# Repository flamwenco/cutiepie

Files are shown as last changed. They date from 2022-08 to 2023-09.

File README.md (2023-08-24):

# cutiepie
A funky little 10.5u with dual 1.75u spacebars. Support for 3u and 4u spacebar bottom row layouts has been added, as well as support for 2x2u's using the 4u top. 2u's are forced stabless, otherwise a redesign of the pcb layout would have been necessitated.

## Layout options


[An ortho pcb](https://github.com/flamwenco/cutiepie/tree/mistress/KiCad%20Project%20Files/ortho%20pcb) is also now available as well.

The vial firmware has been updated to visually support uniform stagger, regular stagger, and ortho, but your existing firmware will also work since the pinouts have not changed.

## Production files
The current version of this pcb that supports all above layouts has been ordered and confirmed to work, but I am not responsible for your orders with a pcb manu. No support will be provided, order at your own risk.

You will also need a daughterboard for this keyboard. It was designed around the ai03 C3 daughterboard.

## Case files
Case files are provided in this repo for 3d printing.

The case is designed around m2 screws and heatset inserts. The top will need 6 M2x4mm inserts, and M2x5mm screws. The daughterboard mounting in the bottom will need 4 M2x3mm inserts, and M2x4mm screws.

The cutouts for the feet in the bottom of the case are sized for primekb feet.

## Special Thanks
- [SST60](https://github.com/dededecline/SST60), this project heavily lifts the rp2040 wiring from it, without it I wouldn't have even known where to start
- 4u spacebar footprint is by [drhigsby](https://github.com/drhigsby)
- Thick plates were created from plates generated by bears' [Keyboard Case Generator](https://github.com/gleorepo/Keyboard-Case-Generator)
- Symmetric case and plate were modified by Chronomap

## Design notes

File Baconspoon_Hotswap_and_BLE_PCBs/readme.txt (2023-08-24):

Included in this directory are several PCB and plate files for Cutiepie by Flamwenco. Pay close attention to compatibility notes. These PCB's and plates are NOT compatible with the original 2x1.75u and 3u case tops, or the original non-symmetrical case bottom. Choose a plate option that will support your desired layout, including stabilizers.
	
-Hotswap, Uniform Stagger
	-Integrated RP2040
	-No ISO Enter support
	-Uses uniform 0.25u stagger, as with the original cutiepie
	-Support for both 2u x 2 and 4u stabilizers.
	-Requires the symmetrical uniform or dual stagger plate for 2u stabilizer support.
	-Requires the symmetrical top and bottom cases with only 2x2u or 4u spacebar support.
	-Compatible with original "cutiepie2040" PCB firmware due to 1-for-1 pinout match.

-Hotswap, Standard Stagger
	-Integrated RP2040
	-No ISO Enter support
	-Option for uniform 0.25u stagger, or traditional 0.5u stagger between the "A" and "Z" row.
	-Support for both 2u x 2 and 4u stabilizers.
	-Requires the symmetrical standard or dual stagger plate for 2u stabilizer support.
	-Requires the symmetrical top and bottom cases with only 2x2u or 4u spacebar support.
	-Compatible with original "cutiepie2040" PCB firmware due to 1-for-1 pinout match.

-Solder Only, Dual Stagger (Uniform and Standard) BLE
	-Integrated nRF52840 via Holyiot-18010-nRF52840 module
	-No ISO Enter support
	-Option for traditional 0.5u stagger between the "A" and "Z" row.
	-Support for both 2u x 2 and 4u stabilizers.
	-Requires the symmetrical standard or dual stagger plate for 2u stabilizer support.
	-Requires the symmetrical top and bottom cases with only 2x2u or 4u spacebar support.
	-Custom ZMK firmware

-Dual Stagger Plate
	-Maintains ISO switch and stabilizers support for future compatibility with symmetrical case PCBs supporting ISO Enter.
	-"Z" row switch cutouts support both standard and uniform stagger.
	-May be difficult to achieve perfect left-to-right alignment with 3-pin switches.
	-Gerbers for FR4 plates included with KiCad project files.

-Standard Stagger and Uniform Stagger Plates
	-Maintains ISO switch and stabilizers support for future compatibility with symmetrical case PCBs supporting ISO Enter.
	-Separate plates for each stagger option for better alignment with 3-pin switches.
	-Gerbers for FR4 plates included with KiCad project files.

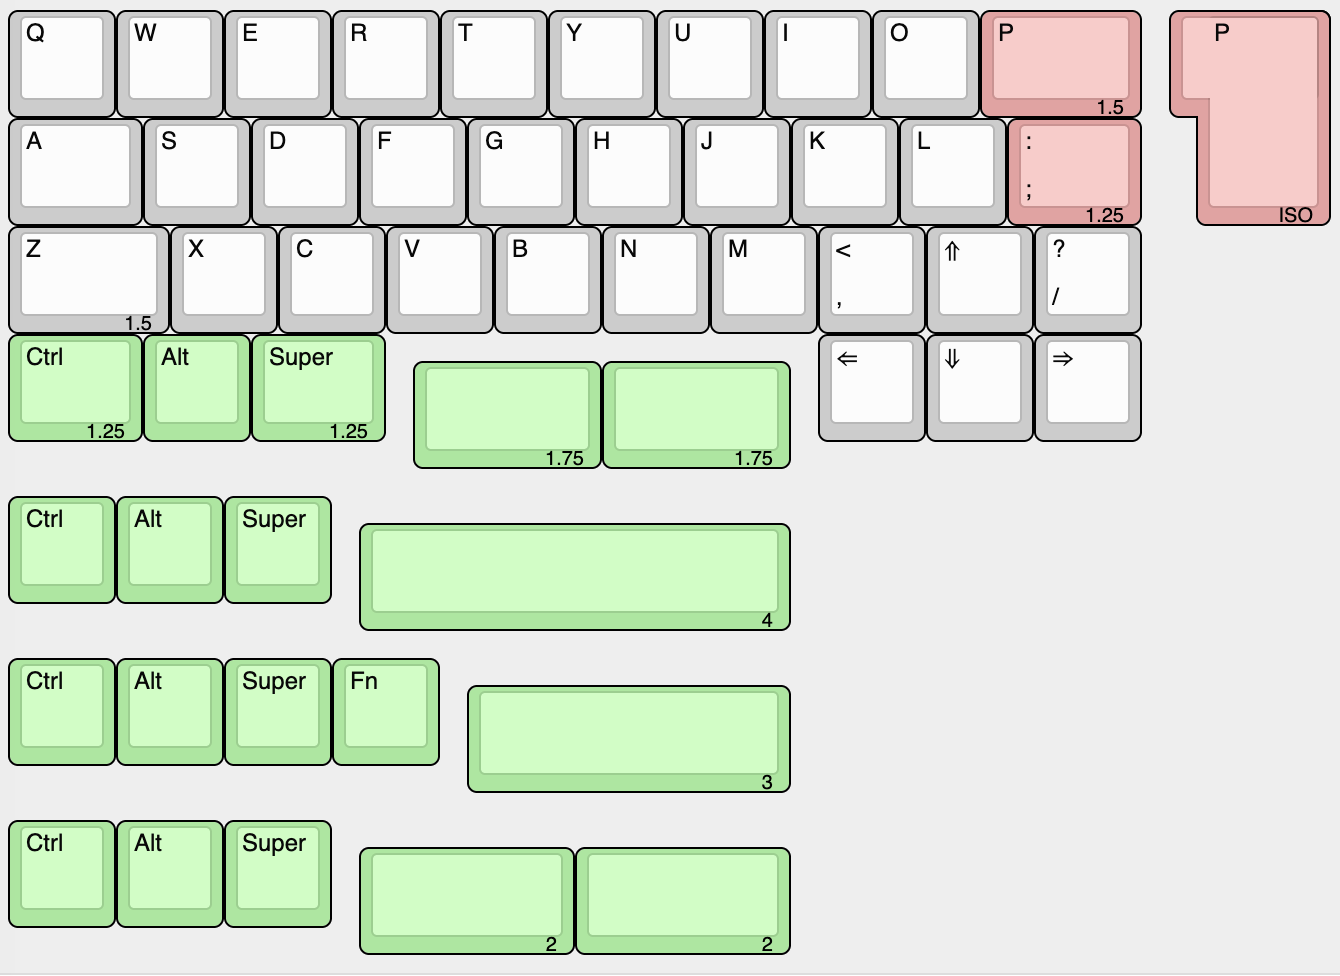
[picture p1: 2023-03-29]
layouts.png

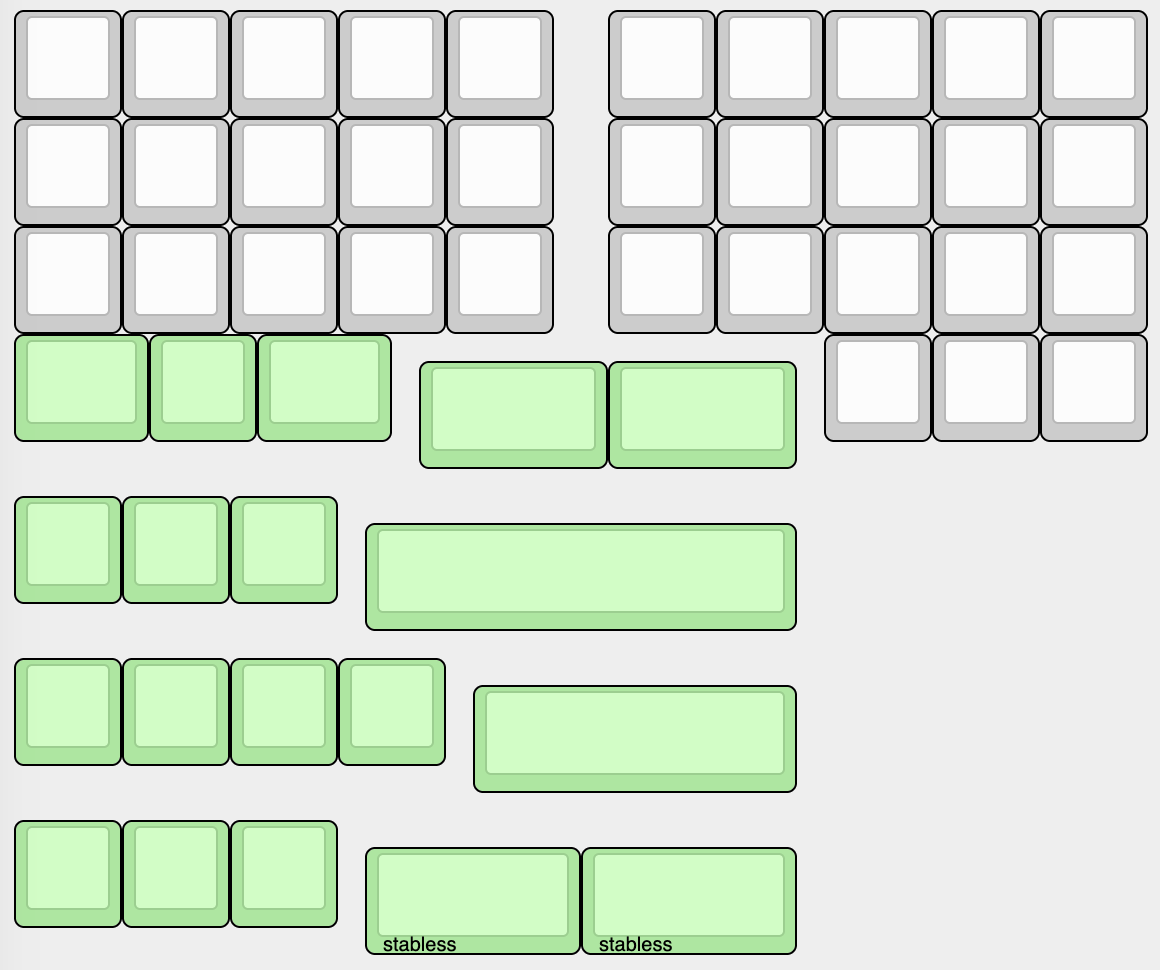
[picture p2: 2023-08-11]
KiCad Project Files/ortho pcb/ortho layouts.png

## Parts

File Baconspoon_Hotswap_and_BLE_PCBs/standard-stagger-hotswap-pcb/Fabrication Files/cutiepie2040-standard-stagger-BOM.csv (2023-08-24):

Comment | Designator | Footprint | JLCPCB Part#(optional)
5K1 | R_Flash2 | R_0402_1005Metric | C103086
5K1 | R_Flash3 | R_0402_1005Metric | C103086
5K1 | R_RST1 | R_0402_1005Metric | C103086
10uF | C_3V-Decoup1 | C_0402_1005Metric | C15525
22pF | C_Crystal1 | C_0402_1005Metric | C1555
22pF | C_Crystal2 | C_0402_1005Metric | C1555
SM04B-SRSS-TB(LF)(SN) | J1 | JST_SH_SM04B-SRSS-TB_1x04-1MP_P1.00mm_Horizontal | C160404
RP2040 | U1 | RP2040-QFN-56 | C2040
27 | R_DATA1 | R_0402_1005Metric | C25100
27 | R_DATA2 | R_0402_1005Metric | C25100
W25Q128JVS | U2 | SOIC-8_5.23x5.23mm_P1.27mm | C2613930
0.1uF | C_1V-Decoup2 | C_0402_1005Metric | C2655418
0.1uF | C_1V-Decoup3 | C_0402_1005Metric | C2655418
0.1uF | C_3V-Decoup3 | C_0402_1005Metric | C2655418
0.1uF | C_3V-Decoup4 | C_0402_1005Metric | C2655418
0.1uF | C_3V-Decoup5 | C_0402_1005Metric | C2655418
0.1uF | C_3V-Decoup6 | C_0402_1005Metric | C2655418
0.1uF | C_3V-Decoup7 | C_0402_1005Metric | C2655418
0.1uF | C_3V-Decoup8 | C_0402_1005Metric | C2655418
0.1uF | C_3V-Decoup9 | C_0402_1005Metric | C2655418
0.1uF | C_Flash1 | C_0402_1005Metric | C2655418
1K | R_Crystal1 | R_0402_1005Metric | C279987
1K | R_Flash1 | R_0402_1005Metric | C279987
CPG151101S11 | MX1 | MXOnly-1U-Hotswap | C2803348
CPG151101S11 | MX10 | MXOnly-1U-Hotswap | C2803348
CPG151101S11 | MX11 | MXOnly-1U-Hotswap | C2803348
CPG151101S11 | MX12 | MXOnly-1U-Hotswap | C2803348
CPG151101S11 | MX13 | MXOnly-1U-Hotswap | C2803348
CPG151101S11 | MX14 | MXOnly-1U-Hotswap | C2803348
CPG151101S11 | MX15 | MXOnly-1U-Hotswap | C2803348
CPG151101S11 | MX16 | MXOnly-1U-Hotswap | C2803348
CPG151101S11 | MX17 | MXOnly-1U-Hotswap | C2803348
CPG151101S11 | MX18 | MXOnly-1U-Hotswap | C2803348
CPG151101S11 | MX19 | MXOnly-2U-Hotswap-ReversedStabilizers | C2803348
CPG151101S11 | MX2 | MXOnly-1.25U-Hotswap | C2803348
CPG151101S11 | MX20 | MXOnly-1U-Hotswap | C2803348
CPG151101S11 | MX21 | MXOnly-1U-Hotswap | C2803348
CPG151101S11 | MX22 | MXOnly-1U-Hotswap | C2803348
CPG151101S11 | MX23 | MXOnly-2U-Hotswap-ReversedStabilizers | C2803348
CPG151101S11 | MX24 | MXOnly-1U-Hotswap | C2803348
CPG151101S11 | MX25 | MXOnly-1U-Hotswap | C2803348
CPG151101S11 | MX26 | MXOnly-1U-Hotswap | C2803348
CPG151101S11 | MX27 | MXOnly-1U-Hotswap | C2803348
CPG151101S11 | MX28 | MXOnly-1U-Hotswap | C2803348
CPG151101S11 | MX29 | MXOnly-1U-Hotswap | C2803348
CPG151101S11 | MX3 | MXOnly-1.5U-Hotswap | C2803348
CPG151101S11 | MX30 | MXOnly-1U-Hotswap | C2803348
CPG151101S11 | MX31 | MXOnly-1U-Hotswap | C2803348
CPG151101S11 | MX32 | MXOnly-1U-Hotswap | C2803348
CPG151101S11 | MX33 | MXOnly-1U-Hotswap | C2803348
CPG151101S11 | MX34 | MXOnly-1U-Hotswap | C2803348
CPG151101S11 | MX35 | MXOnly-1.5U-Hotswap | C2803348
CPG151101S11 | MX36 | MXOnly-1.25U-Hotswap | C2803348
CPG151101S11 | MX37 | MXOnly-1U-Hotswap | C2803348
CPG151101S11 | MX38 | MXOnly-1U-Hotswap | C2803348
CPG151101S11 | MX4 | MXOnly-1U-Hotswap | C2803348
CPG151101S11 | MX5 | MXOnly-1U-Hotswap | C2803348
CPG151101S11 | MX6 | MXOnly-1U-Hotswap | C2803348
CPG151101S11 | MX7 | MXOnly-1U-Hotswap | C2803348
CPG151101S11 | MX8 | MXOnly-1U-Hotswap | C2803348
CPG151101S11 | MX9 | MXOnly-1U-Hotswap | C2803348
BOOTSEL | SW1 | SW_SPST_TL3342 | C318884
RESET | SW2 | SW_SPST_TL3342 | C318884
1uF | C_1V-Decoup1 | C_0402_1005Metric | C52923
1uF | C_3V-Decoup2 | C_0402_1005Metric | C52923
1uF | C_LD1 | C_0402_1005Metric | C52923
1uF | C_LD2 | C_0402_1005Metric | C52923
XC6206P332MR | U3 | SOT-23 | C5446
1N4148W | D1 | D_SOD-123 | C81598
1N4148W | D10 | D_SOD-123 | C81598
1N4148W | D11 | D_SOD-123 | C81598
1N4148W | D12 | D_SOD-123 | C81598
1N4148W | D13 | D_SOD-123 | C81598
1N4148W | D14 | D_SOD-123 | C81598
1N4148W | D15 | D_SOD-123 | C81598
1N4148W | D16 | D_SOD-123 | C81598
1N4148W | D17 | D_SOD-123 | C81598
1N4148W | D18 | D_SOD-123 | C81598
1N4148W | D19 | D_SOD-123 | C81598
1N4148W | D2 | D_SOD-123 | C81598
1N4148W | D20 | D_SOD-123 | C81598
1N4148W | D21 | D_SOD-123 | C81598
1N4148W | D22 | D_SOD-123 | C81598
1N4148W | D23 | D_SOD-123 | C81598
1N4148W | D24 | D_SOD-123 | C81598
1N4148W | D25 | D_SOD-123 | C81598
1N4148W | D26 | D_SOD-123 | C81598
1N4148W | D27 | D_SOD-123 | C81598
1N4148W | D28 | D_SOD-123 | C81598
1N4148W | D29 | D_SOD-123 | C81598
1N4148W | D3 | D_SOD-123 | C81598
1N4148W | D30 | D_SOD-123 | C81598
1N4148W | D31 | D_SOD-123 | C81598
1N4148W | D32 | D_SOD-123 | C81598
1N4148W | D33 | D_SOD-123 | C81598
1N4148W | D34 | D_SOD-123 | C81598
1N4148W | D35 | D_SOD-123 | C81598
1N4148W | D36 | D_SOD-123 | C81598
1N4148W | D37 | D_SOD-123 | C81598
1N4148W | D4 | D_SOD-123 | C81598
1N4148W | D5 | D_SOD-123 | C81598
1N4148W | D6 | D_SOD-123 | C81598
1N4148W | D7 | D_SOD-123 | C81598
1N4148W | D8 | D_SOD-123 | C81598
1N4148W | D9 | D_SOD-123 | C81598
X322512MSB4SI | Y1 | Crystal_SMD_3225-4Pin_3.2x2.5mm | C9002

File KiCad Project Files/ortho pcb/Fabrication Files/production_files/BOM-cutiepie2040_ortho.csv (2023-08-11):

Comment | Designator | Footprint | LCSC
1k | R_Crystal1,R_Flash1,R_RST1 | R_0402_1005Metric | C11702
SM04B | J1 | JST_SH_SM04B-SRSS-TB_1x04-1MP_P1.00mm_Horizontal | C145956
.1u | C_1V-Decoup2,C_1V-Decoup3,C_3V-Decoup3,C_3V-Decoup4,C_3V-Decoup5,C_3V-Decoup6,C_3V-Decoup7,C_3V-Decoup8,C_3V-Decoup9,C_Flash1 | C_0402_1005Metric | C1525
10u | C_3V-Decoup1 | C_0402_1005Metric | C15525
22pF | C_Crystal1,C_Crystal2 | C_0402_1005Metric | C1555
27 | R_DATA1,R_DATA2 | R_0402_1005Metric | C203147
RP2040 | U1 | RP2040-QFN-56 | C2040
1u | C_1V-Decoup1,C_3V-Decoup2,C_LD1,C_LD2 | C_0402_1005Metric | C52923
XC6206PxxxMR | U3 | SOT-23 | C5446
D_Small | D1,D10,D11,D12,D13,D14,D15,D16,D17,D18,D19,D2,D20,D21,D22,D23,D24,D25,D26,D27,D28,D29,D3,D30,D31,D32,D33,D34,D35,D36,D37,D38,D4,D5,D6,D7,D8,D9 | D_SOD-123 | C64898
12MHz | Y1 | Crystal_SMD_3225-4Pin_3.2x2.5mm | C9002
W25Q128JVS | U2 | SOIC-8_5.23x5.23mm_P1.27mm | C97521
MX-NoLED | MX2 | MXOnly-1U-NoLED
MX-NoLED | MX36 | MXOnly-1U-NoLED
Reset | SW1 | PinHeader_1x02_P1.27mm_Vertical
MX-NoLED | MX38 | MXOnly-1U-NoLED
MX-NoLED | MX37 | MXOnly-1U-NoLED
MX-NoLED | MX35 | MXOnly-1U-NoLED
MX-NoLED | MX34 | MXOnly-1U-NoLED
MX-NoLED | MX33 | MXOnly-1U-NoLED
MX-NoLED | MX32 | MXOnly-1U-NoLED
MX-NoLED | MX31 | MXOnly-1U-NoLED
MX-NoLED | MX30 | MXOnly-1U-NoLED
MX-NoLED | MX29 | MXOnly-1U-NoLED
MX-NoLED | MX28 | MXOnly-1U-NoLED
MX-NoLED | MX27 | MXOnly-1U-NoLED
MX-NoLED | MX26 | MXOnly-1U-NoLED
MX-NoLED | MX25 | MXOnly-1U-NoLED
MX-NoLED | MX24 | MXOnly-1U-NoLED
MX-NoLED | MX23 | MXOnly-1.75U-NoLED
MX-NoLED | MX22 | MXOnly-1U-NoLED
MX-NoLED | MX21 | MXOnly-1U-NoLED
MX-NoLED | MX20 | MXOnly-1U-NoLED
MX-NoLED | MX19 | MXOnly-2U-NoLED
MX-NoLED | MX18 | MXOnly-1U-NoLED
MX-NoLED | MX17 | MXOnly-1U-NoLED
MX-NoLED | MX16 | MXOnly-1U-NoLED
MX-NoLED | MX15 | MXOnly-1U-NoLED
MX-NoLED | MX14 | MXOnly-1U-NoLED
MX-NoLED | MX13 | MXOnly-1U-NoLED
MX-NoLED | MX12 | MXOnly-1U-NoLED
MX-NoLED | MX11 | MXOnly-1U-NoLED
MX-NoLED | MX10 | MXOnly-1U-NoLED
MX-NoLED | MX9 | MXOnly-1U-NoLED
MX-NoLED | MX8 | MXOnly-1U-NoLED
MX-NoLED | MX7 | MXOnly-1U-NoLED
MX-NoLED | MX6 | MXOnly-1U-NoLED
MX-NoLED | MX5 | MXOnly-1U-NoLED
MX-NoLED | MX4 | MXOnly-1.25U-NoLED
MX-NoLED | MX3 | MXOnly-1U-NoLED
MX-NoLED | MX1 | MXOnly-1U-NoLED
SWD | J2 | PinHeader_1x05_P2.54mm_Vertical

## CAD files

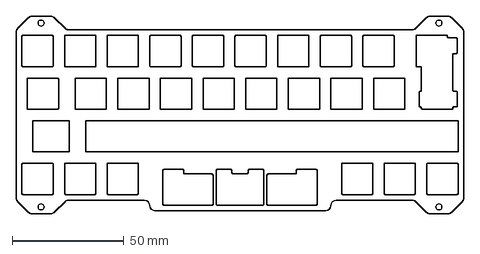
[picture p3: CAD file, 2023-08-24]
Baconspoon_Hotswap_and_BLE_PCBs/dual-stagger-fr4-plate/dual-stagger-cutiepie-plate.dxf
200.0 x 88.2 mm

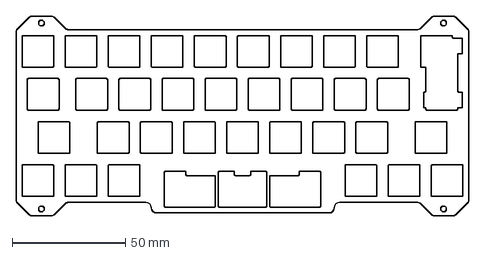
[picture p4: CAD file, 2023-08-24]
Baconspoon_Hotswap_and_BLE_PCBs/standard-stagger-fr4-plate/standard-stagger-cutiepie-plate.dxf
200.0 x 88.2 mm

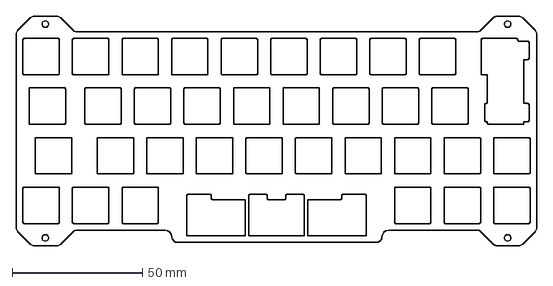
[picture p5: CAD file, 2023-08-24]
Baconspoon_Hotswap_and_BLE_PCBs/uniform-stagger-fr4-plate/uniform-stagger-cutiepie-plate.dxf
200.0 x 88.2 mm

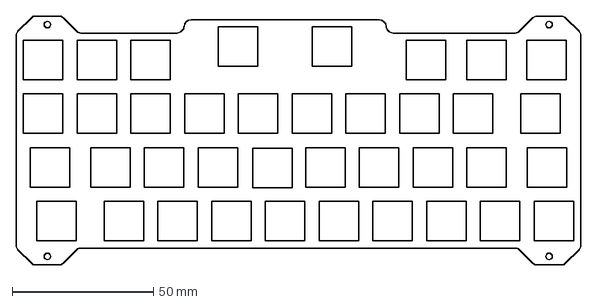
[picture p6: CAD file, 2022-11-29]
Case Files/2x1.75u layout case/plate.dxf
200.0 x 88.2 mm

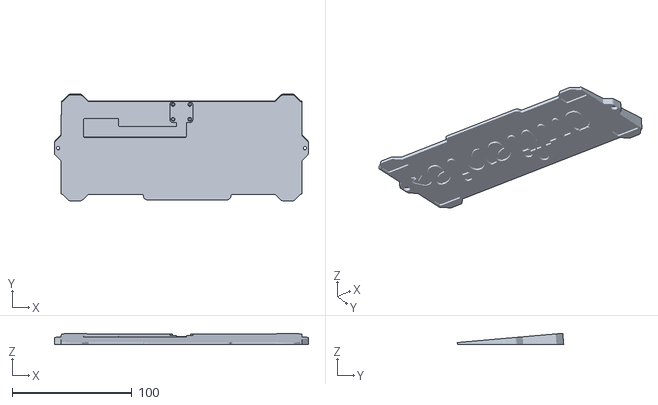
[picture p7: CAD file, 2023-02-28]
Case Files/Bottom (DSS Hail Satan ver).stl
212.5 x 89.2 x 9.55

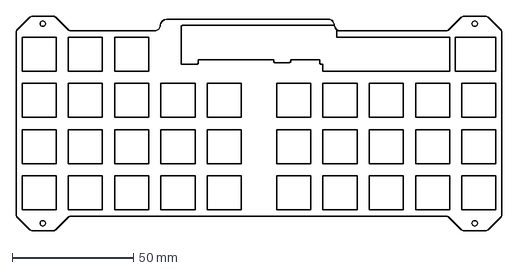
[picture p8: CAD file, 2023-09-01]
Case Files/Plates/Universal Ortho Plate.dxf
200.0 x 88.2 mm

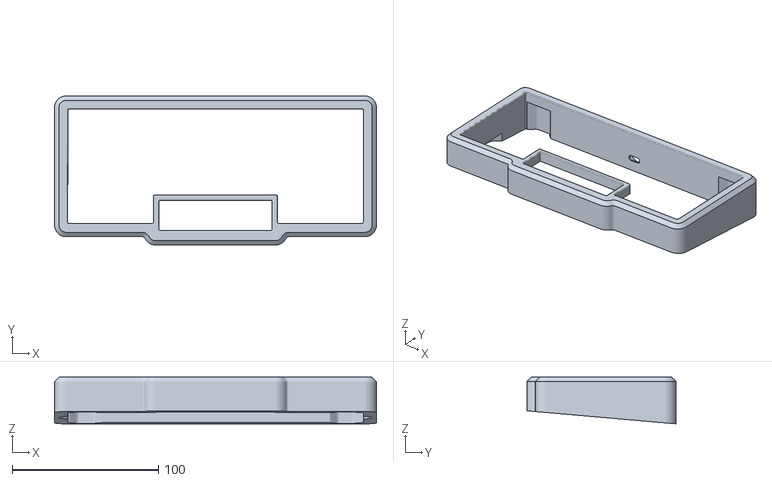
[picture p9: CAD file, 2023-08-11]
Case Files/Symmetrical 4u 2x2u Case/symmetric_cutiepie_4u_top v1.stl
220.0 x 101.9 x 31.9

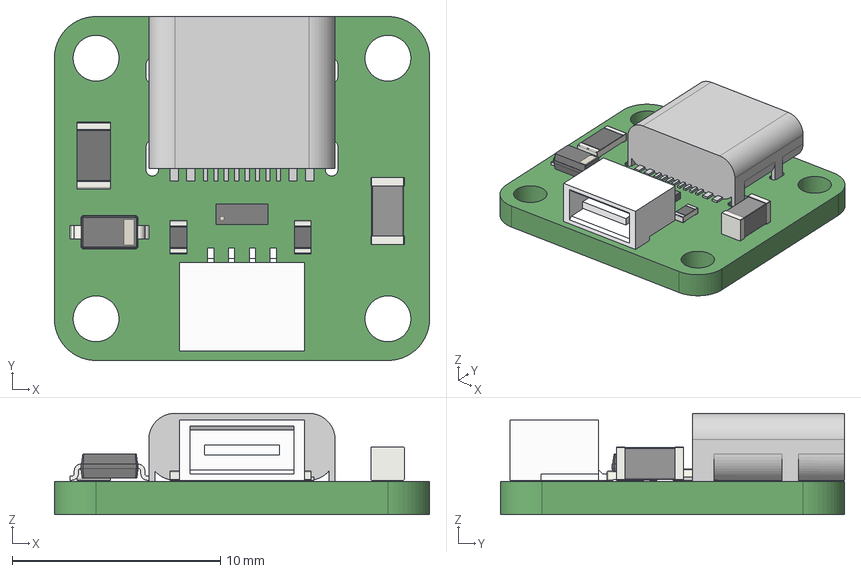
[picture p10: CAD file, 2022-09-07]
Design Files/Unified-Daughterboard v1.step
18.0 x 16.5 x 4.86 mm

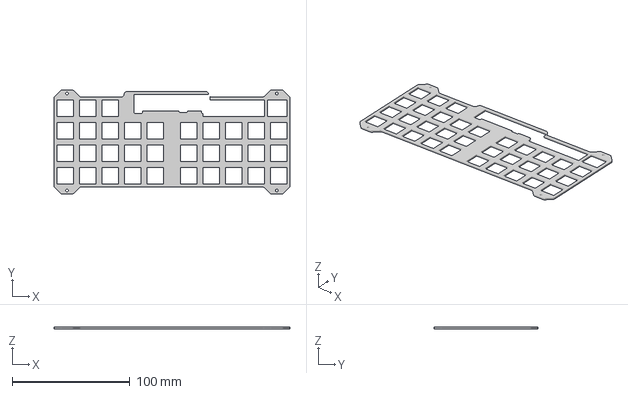
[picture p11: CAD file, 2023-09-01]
Case Files/Plates/cutiepie ortho plate v10.3mf
200.0 x 88.2 x 1.50 mm

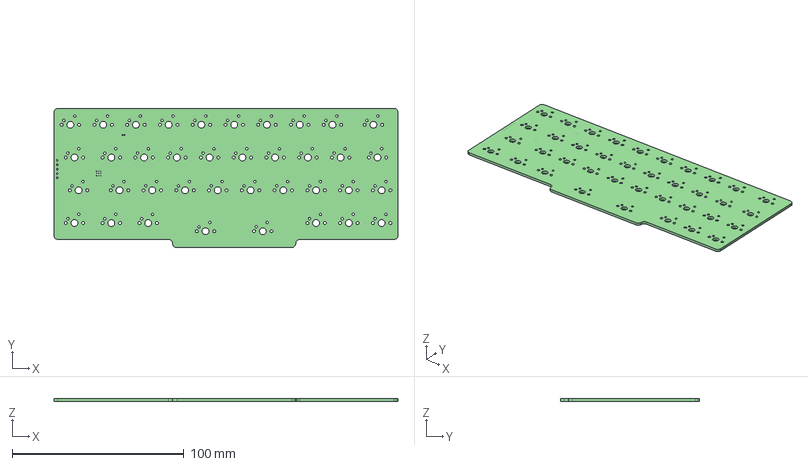
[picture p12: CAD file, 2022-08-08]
Design Files/shortiepie2040.STEP
200.0 x 81.0 x 1.60 mm

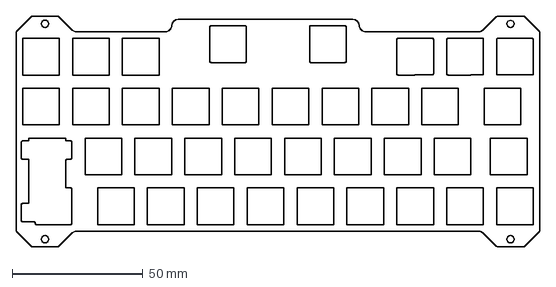
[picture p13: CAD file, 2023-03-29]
Case Files/Plates/2x2u Plate.dxf
200.0 x 88.2 mm

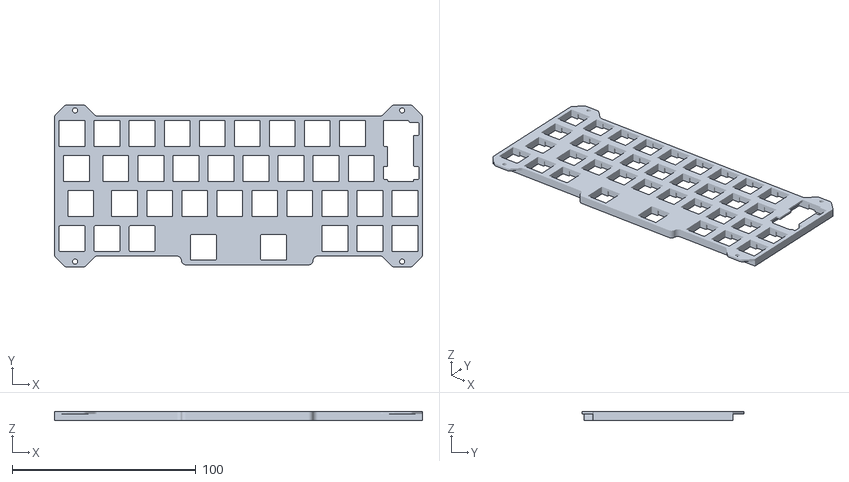
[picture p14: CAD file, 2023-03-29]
Case Files/Plates/2x2u Thick Plate.stl
200.0 x 88.2 x 5.00

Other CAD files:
Case Files/Tops/3u Top.stl
Case Files/Bottom.stl
Case Files/Symmetrical 4u 2x2u Case/symmetric_cutiepie_weight v1.stl
Case Files/Tops/4u 2x2u Top.stl
Case Files/Symmetrical 4u 2x2u Case/symmetric_cutiepie_4u_top.step
Case Files/Tops/2x1.75u Top.stl
Case Files/Plates/2x1.75u Plate.dxf
Case Files/Plates/2x1.75u Thick Plate.stl
Case Files/Plates/3u Plate.dxf
Case Files/Plates/3u Thick Plate.stl
Case Files/Plates/4u Plate.dxf
Case Files/Plates/4u Thick Plate.stl
Case Files/Symmetrical 4u 2x2u Case/symmetric_cutiepie_4u_plate.dxf
Case Files/Symmetrical 4u 2x2u Case/symmetric_cutiepie_weight.step

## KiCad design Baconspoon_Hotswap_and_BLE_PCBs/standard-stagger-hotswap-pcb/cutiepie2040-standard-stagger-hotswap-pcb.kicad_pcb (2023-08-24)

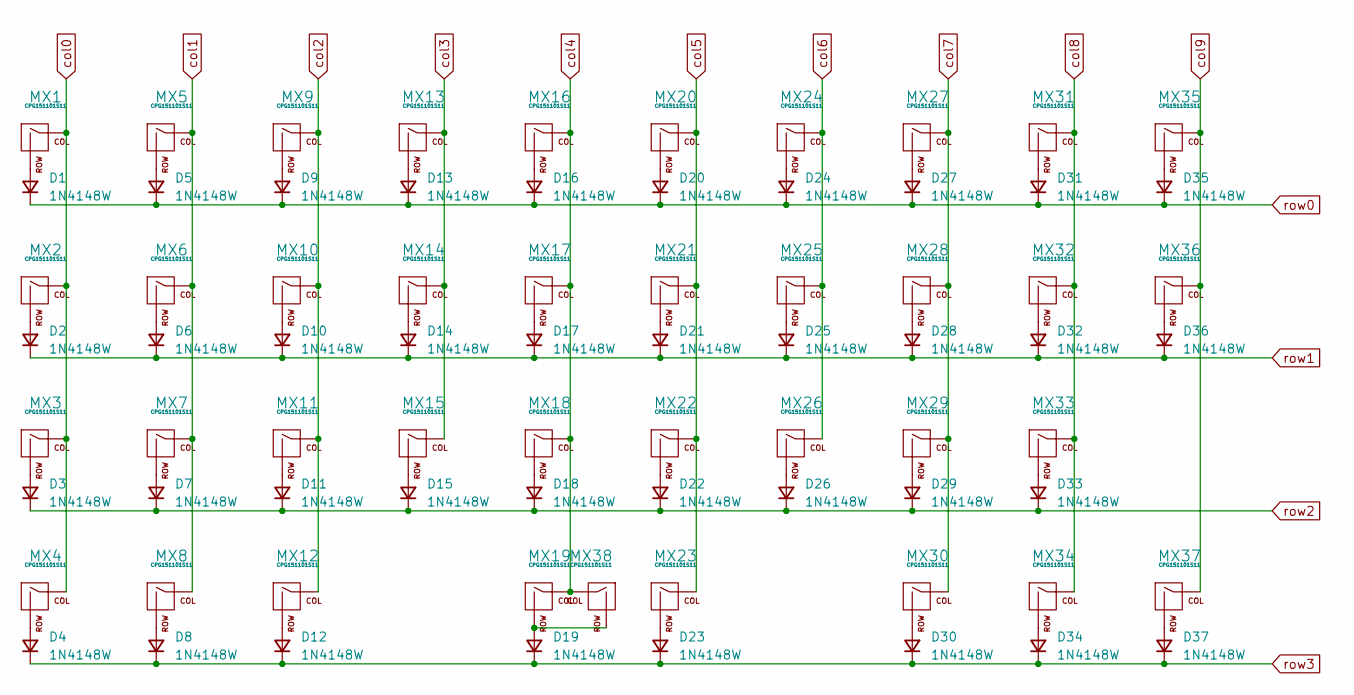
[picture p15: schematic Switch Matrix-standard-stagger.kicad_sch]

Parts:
D1, D2, D3, D4, D5, D6, D7, D8, D9, D10, D11, D12, D13, D14, D15, D16, D17, D18, D19, D20, D21, D22, D23, D24, D25, D26, D27, D28, D29, D30, D31, D32, D33, D34, D35, D36, D37: 1N4148W; D_SOD-123
MX1, MX4, MX5, MX6, MX7, MX8, MX9, MX10, MX11, MX12, MX13, MX14, MX15, MX16, MX17, MX18, MX20, MX21, MX22, MX24, MX25, MX26, MX27, MX28, MX29, MX30, MX31, MX32, MX34, MX37: CPG151101S11; MXOnly-1U-Hotswap; LCSC C2803348
MX2, MX36: CPG151101S11; MXOnly-1.25U-Hotswap; LCSC C2803348
MX3, MX33: CPG151101S11; MXOnly-1.75U-Hotswap; LCSC C2803348
MX19, MX23, MX38: CPG151101S11; MXOnly-2U-Hotswap-ReversedStabilizers; LCSC C2803348
MX35: CPG151101S11; MXOnly-1.5U-Hotswap; LCSC C2803348

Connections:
unnamed: D1.2 (A), MX1.2 (ROW)
unnamed: D2.2 (A), MX2.2 (ROW)
unnamed: D3.2 (A), MX3.2 (ROW)
unnamed: D4.2 (A), MX4.2 (ROW)
unnamed: D5.2 (A), MX5.2 (ROW)
unnamed: D6.2 (A), MX6.2 (ROW)
unnamed: D7.2 (A), MX7.2 (ROW)
unnamed: D8.2 (A), MX8.2 (ROW)
unnamed: D9.2 (A), MX9.2 (ROW)
unnamed: D10.2 (A), MX10.2 (ROW)
unnamed: D11.2 (A), MX11.2 (ROW)
unnamed: D12.2 (A), MX12.2 (ROW)
unnamed: D13.2 (A), MX13.2 (ROW)
unnamed: D14.2 (A), MX14.2 (ROW)
unnamed: D15.2 (A), MX15.2 (ROW)
unnamed: D16.2 (A), MX16.2 (ROW)
unnamed: D17.2 (A), MX17.2 (ROW)
unnamed: D18.2 (A), MX18.2 (ROW)
unnamed: D19.2 (A), MX19.2 (ROW), MX38.2 (ROW)
unnamed: D20.2 (A), MX20.2 (ROW)
unnamed: D21.2 (A), MX21.2 (ROW)
unnamed: D22.2 (A), MX22.2 (ROW)
unnamed: D23.2 (A), MX23.2 (ROW)
unnamed: D24.2 (A), MX24.2 (ROW)
unnamed: D25.2 (A), MX25.2 (ROW)
unnamed: D26.2 (A), MX26.2 (ROW)
unnamed: D27.2 (A), MX27.2 (ROW)
unnamed: D28.2 (A), MX28.2 (ROW)
unnamed: D29.2 (A), MX29.2 (ROW)
unnamed: D30.2 (A), MX30.2 (ROW)
unnamed: D31.2 (A), MX31.2 (ROW)
unnamed: D32.2 (A), MX32.2 (ROW)
unnamed: D33.2 (A), MX33.2 (ROW)
unnamed: D34.2 (A), MX34.2 (ROW)
unnamed: D35.2 (A), MX35.2 (ROW)
unnamed: D36.2 (A), MX36.2 (ROW)
unnamed: D37.2 (A), MX37.2 (ROW)
col0: MX1.1 (COL), MX2.1 (COL), MX3.1 (COL), MX4.1 (COL); also elsewhere on the board
col1: MX5.1 (COL), MX6.1 (COL), MX7.1 (COL), MX8.1 (COL); also elsewhere on the board
col2: MX9.1 (COL), MX10.1 (COL), MX11.1 (COL), MX12.1 (COL); also elsewhere on the board
col3: MX13.1 (COL), MX14.1 (COL), MX15.1 (COL); also elsewhere on the board
col4: MX16.1 (COL), MX17.1 (COL), MX18.1 (COL), MX19.1 (COL), MX38.1 (COL); also elsewhere on the board
col5: MX20.1 (COL), MX21.1 (COL), MX22.1 (COL), MX23.1 (COL); also elsewhere on the board
col6: MX24.1 (COL), MX25.1 (COL), MX26.1 (COL); also elsewhere on the board
col7: MX27.1 (COL), MX28.1 (COL), MX29.1 (COL), MX30.1 (COL); also elsewhere on the board
col8: MX31.1 (COL), MX32.1 (COL), MX33.1 (COL), MX34.1 (COL); also elsewhere on the board
col9: MX35.1 (COL), MX36.1 (COL), MX37.1 (COL); also elsewhere on the board
row0: D1.1 (K), D5.1 (K), D9.1 (K), D13.1 (K), D16.1 (K), D20.1 (K), D24.1 (K), D27.1 (K), D31.1 (K), D35.1 (K); also elsewhere on the board
row1: D2.1 (K), D6.1 (K), D10.1 (K), D14.1 (K), D17.1 (K), D21.1 (K), D25.1 (K), D28.1 (K), D32.1 (K), D36.1 (K); also elsewhere on the board
row2: D3.1 (K), D7.1 (K), D11.1 (K), D15.1 (K), D18.1 (K), D22.1 (K), D26.1 (K), D29.1 (K), D33.1 (K); also elsewhere on the board
row3: D4.1 (K), D8.1 (K), D12.1 (K), D19.1 (K), D23.1 (K), D30.1 (K), D34.1 (K), D37.1 (K); also elsewhere on the board

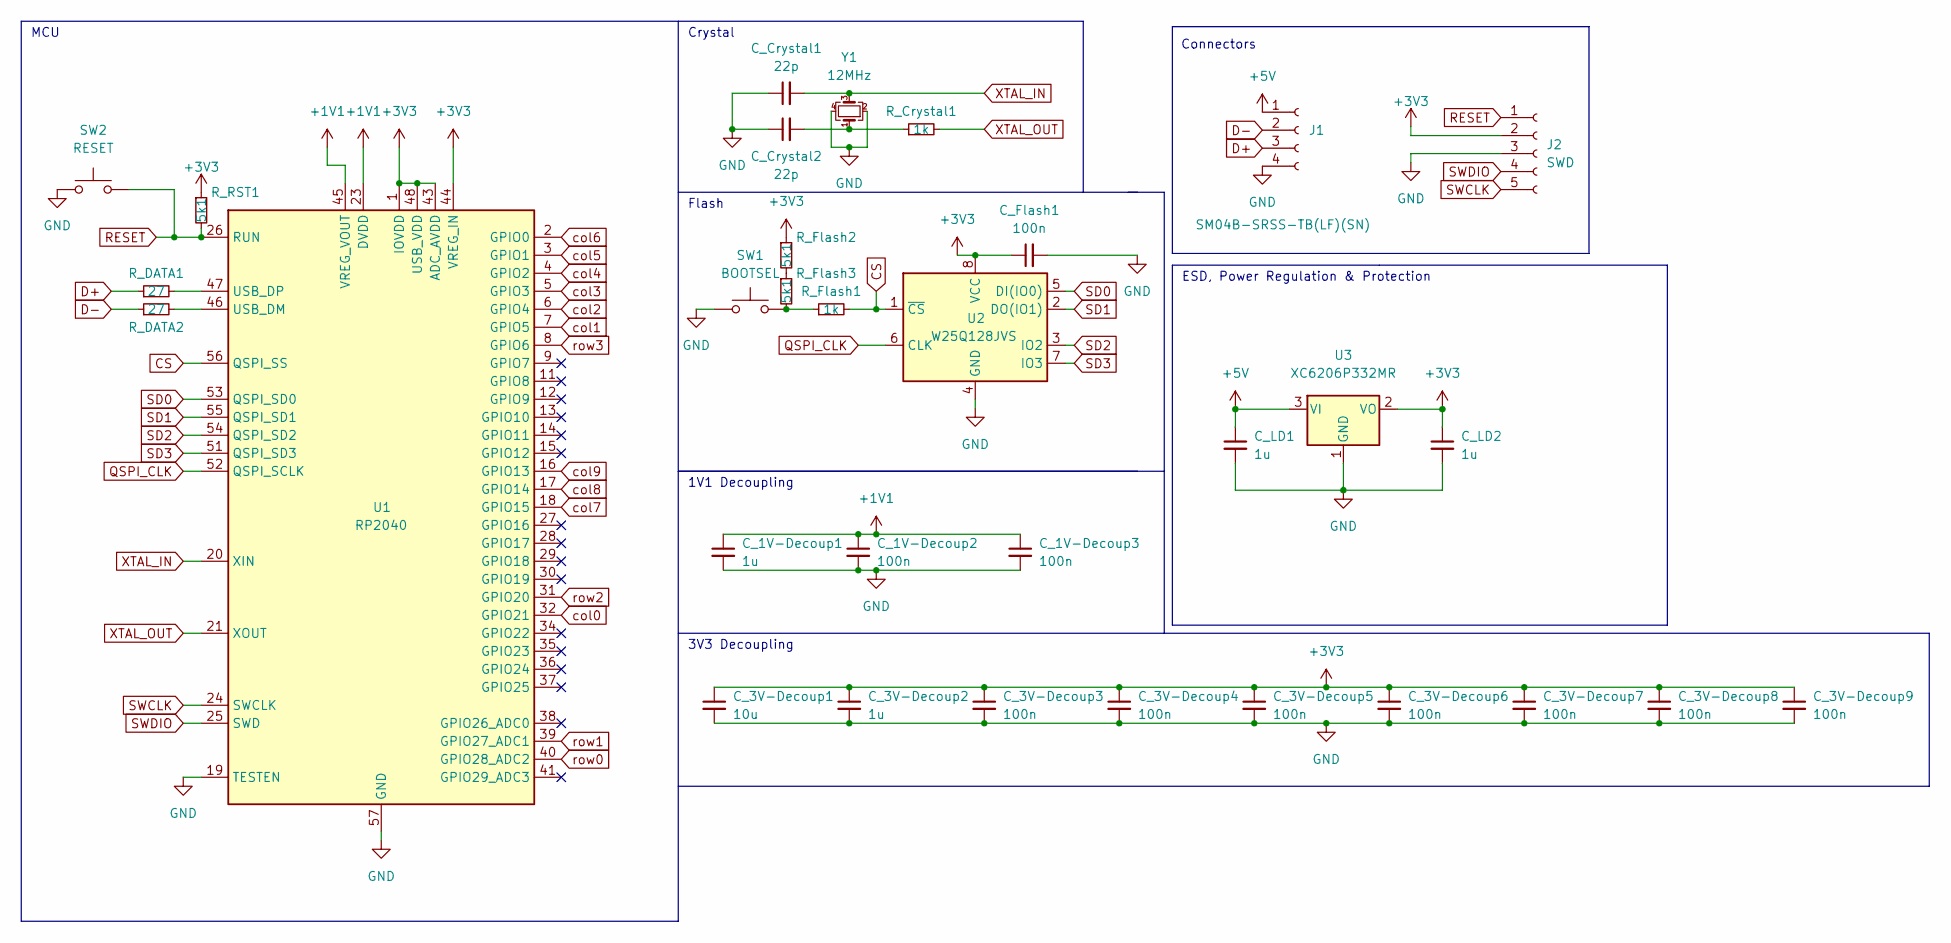
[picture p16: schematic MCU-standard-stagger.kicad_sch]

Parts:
C_1V-Decoup1, C_3V-Decoup2: 1u; C_0402_1005Metric
C_1V-Decoup2, C_1V-Decoup3, C_3V-Decoup3, C_3V-Decoup4, C_3V-Decoup5, C_3V-Decoup6, C_3V-Decoup7, C_3V-Decoup8, C_3V-Decoup9: 100n; C_0402_1005Metric
C_3V-Decoup1: 10u; C_0402_1005Metric
C_Crystal1, C_Crystal2: 22p; C_0402_1005Metric
C_Flash1: 100n; C_0402_1005Metric
C_LD1, C_LD2: 1u; C_0402_1005Metric
J1: SM04B-SRSS-TB(LF)(SN); JST_SH_SM04B-SRSS-TB_1x04-1MP_P1.00mm_Horizontal; LCSC C160404
J2: SWD; PinHeader_1x05_P2.54mm_Vertical
R_Crystal1: 1k; R_0402_1005Metric
R_DATA1, R_DATA2: 27; R_0402_1005Metric
R_Flash1: 1k; R_0402_1005Metric
R_Flash2, R_Flash3: 5k1; R_0402_1005Metric
R_RST1: 5k1; R_0402_1005Metric
SW1: BOOTSEL; SW_SPST_TL3342; LCSC C318884
SW2: RESET; SW_SPST_TL3342; LCSC C318884
U1: RP2040; RP2040-QFN-56; LCSC C2040
U2: W25Q128JVS; SOIC-8_5.23x5.23mm_P1.27mm; LCSC C2613930
U3: XC6206P332MR; SOT-23; LCSC C5446
Y1: 12MHz; Crystal_SMD_3225-4Pin_3.2x2.5mm; LCSC C9002

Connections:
+1V1: C_1V-Decoup1.1, C_1V-Decoup2.1, C_1V-Decoup3.1, U1.23 (DVDD), U1.45 (VREG_VOUT), U1.50 (DVDD)
+3V3: C_3V-Decoup1.1, C_3V-Decoup2.1, C_3V-Decoup3.1, C_3V-Decoup4.1, C_3V-Decoup5.1, C_3V-Decoup6.1, C_3V-Decoup7.1, C_3V-Decoup8.1, C_3V-Decoup9.1, C_Flash1.1, C_LD2.1, J2.2, R_Flash2.1, R_RST1.1, U1.1 (IOVDD), U1.10 (IOVDD), U1.22 (IOVDD), U1.33 (IOVDD), U1.42 (IOVDD), U1.43 (ADC_AVDD), U1.44 (VREG_IN), U1.48 (USB_VDD), U1.49 (IOVDD), U2.8 (VCC), U3.2 (VO)
+5V: C_LD1.1, J1.1, U3.3 (VI)
CS: R_Flash1.2, U1.56 (QSPI_SS), U2.1 (~CS)
D+: J1.3, R_DATA1.1
D-: J1.2, R_DATA2.1
GND: C_1V-Decoup1.2, C_1V-Decoup2.2, C_1V-Decoup3.2, C_3V-Decoup1.2, C_3V-Decoup2.2, C_3V-Decoup3.2, C_3V-Decoup4.2, C_3V-Decoup5.2, C_3V-Decoup6.2, C_3V-Decoup7.2, C_3V-Decoup8.2, C_3V-Decoup9.2, C_Crystal1.1, C_Crystal2.1, C_Flash1.2, C_LD1.2, C_LD2.2, J1.4, J2.3, SW1.1, SW2.1, U1.19 (TESTEN), U1.57 (GND), U2.4 (GND), U3.1 (GND), Y1.2, Y1.4
unnamed: C_Crystal2.2, R_Crystal1.1, Y1.1
unnamed: R_Flash1.1, R_Flash3.2, SW1.2
unnamed: R_Flash2.2, R_Flash3.1
unnamed: R_DATA2.2, U1.46 (USB_DM)
unnamed: R_DATA1.2, U1.47 (USB_DP)
QSPI_CLK: U1.52 (QSPI_SCLK), U2.6 (CLK)
RESET: J2.1, R_RST1.2, SW2.2, U1.26 (RUN)
SD0: U1.53 (QSPI_SD0), U2.5 (DI(IO0))
SD1: U1.55 (QSPI_SD1), U2.2 (DO(IO1))
SD2: U1.54 (QSPI_SD2), U2.3 (IO2)
SD3: U1.51 (QSPI_SD3), U2.7 (IO3)
SWCLK: J2.5, U1.24 (SWCLK)
SWDIO: J2.4, U1.25 (SWD)
XTAL_IN: C_Crystal1.2, U1.20 (XIN), Y1.3
XTAL_OUT: R_Crystal1.2, U1.21 (XOUT)
col0: U1.32 (GPIO21); also elsewhere on the board
col1: U1.7 (GPIO5); also elsewhere on the board
col2: U1.6 (GPIO4); also elsewhere on the board
col3: U1.5 (GPIO3); also elsewhere on the board
col4: U1.4 (GPIO2); also elsewhere on the board
col5: U1.3 (GPIO1); also elsewhere on the board
col6: U1.2 (GPIO0); also elsewhere on the board
col7: U1.18 (GPIO15); also elsewhere on the board
col8: U1.17 (GPIO14); also elsewhere on the board
col9: U1.16 (GPIO13); also elsewhere on the board
row0: U1.40 (GPIO28_ADC2); also elsewhere on the board
row1: U1.39 (GPIO27_ADC1); also elsewhere on the board
row2: U1.31 (GPIO20); also elsewhere on the board
row3: U1.8 (GPIO6); also elsewhere on the board

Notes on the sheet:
Connectors
1V1 Decoupling
ESD, Power Regulation & Protection
Crystal
MCU
Flash
3V3 Decoupling

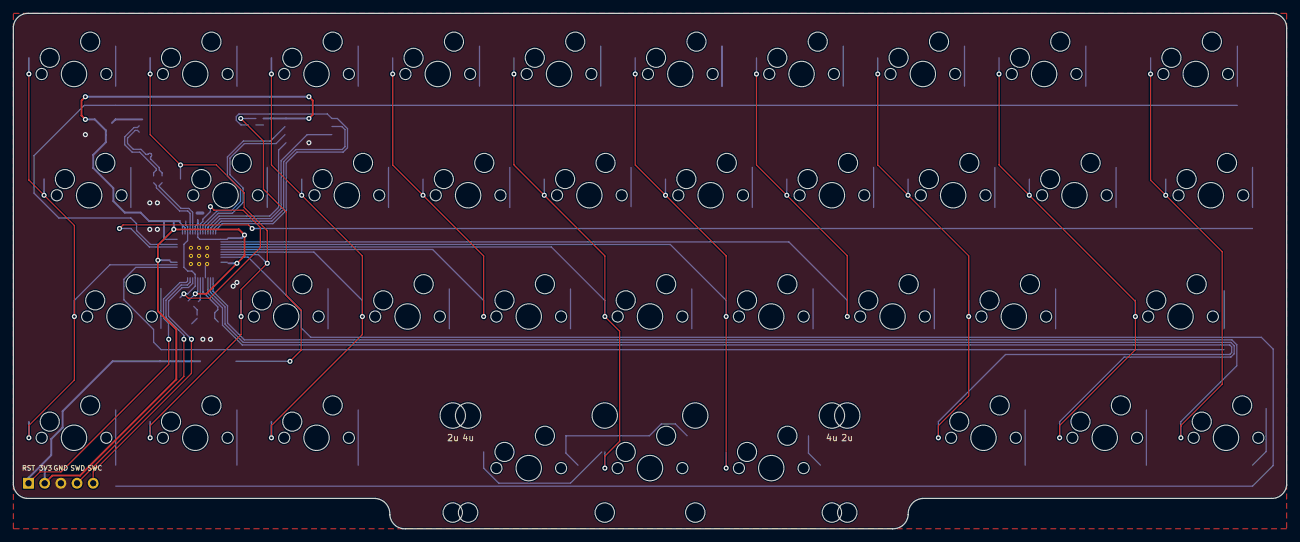
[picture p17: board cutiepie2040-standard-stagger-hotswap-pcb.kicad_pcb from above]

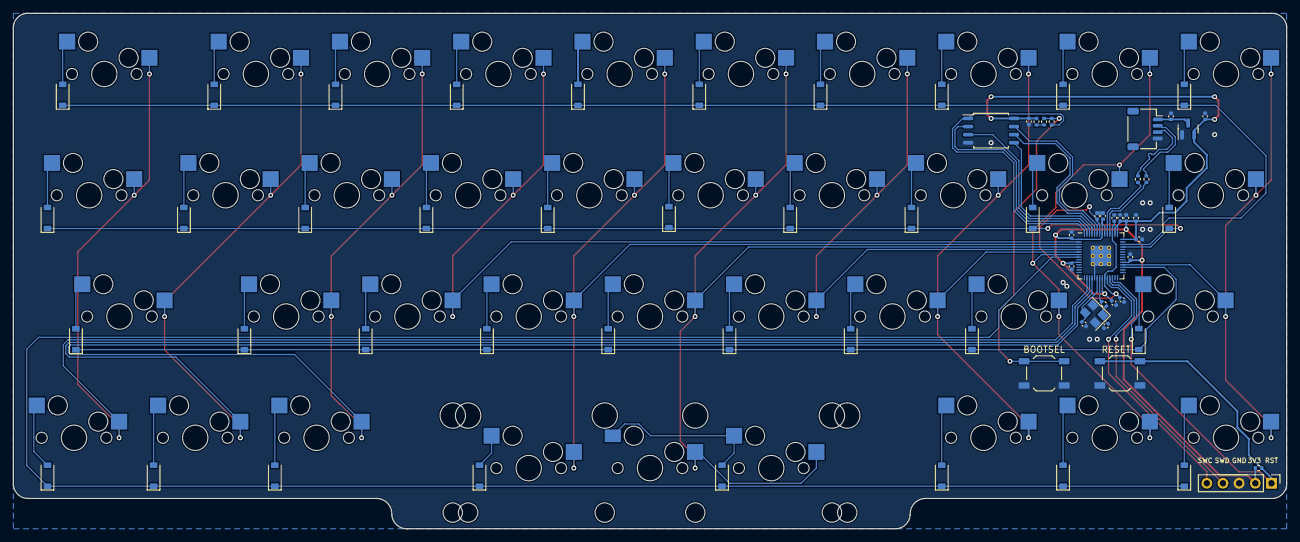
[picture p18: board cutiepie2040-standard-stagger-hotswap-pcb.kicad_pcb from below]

Board: 2 copper layers, 200.0 x 81.0 mm, 107 parts (107 on the bottom side), 73 nets.

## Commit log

2022-08-06 Create project and MCU schematic
    [MCU.kicad_sch, Misc.kicad_sch, Switch Matrix.kicad_sch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]
2022-08-08 Complete schematic aside from switch matrix, and rename project
    [Misc.kicad_sch, USB.kicad_sch, shortiepie2040.kicad_pcb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]
2022-08-08 Finish schematic, annotate footprints, start pcb creation
    [MCU.kicad_sch, Misc.kicad_sch, Switch Matrix.kicad_sch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]
2022-08-08 Finish PCB and create production files
    [BOM-shortiepie2040.csv, MCU.kicad_sch, Switch Matrix.kicad_sch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]
2022-08-08 Create step file of pcb
    [shortiepie2040.STEP]
2022-08-11 Update PCB step
    [shortiepie2040.kicad_pcb]
2022-09-07 Create rough case, update name
    [BOM-cutiepie2040.csv, Unified-Daughterboard v1.step, bottom.stl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]
2022-09-08 Organize case files ahead of possible future cases
    [bottom.stl, plate.dxf, top.stl]
2022-11-08 Update files for current untested pcb, and update readme
    [BOM-cutiepie2040.csv, BOM-shortiepie2040.csv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]
2022-11-29 Redesign case for heat set inserts
    [bottom.stl, plate.dxf, top.stl]
2023-02-07 Update gerbers to fix some routing issues for the new layout
    [BOM-cutiepie2040.csv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]
2023-02-11 pcb updates
2023-02-24 Update pcb & step
2023-02-27 Initial commit for updated case
    [2x1.75u Plate.dxf, 2x1.75u Thick Plate.stl, 2x1.75u Top.stl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]
2023-02-28 Add hail satan bottom too cuz wynaut
    [Bottom (DSS Hail Satan ver).stl]
2023-03-29 Add 2u support to pcb
    [BOM-cutiepie2040.csv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]
2023-03-29 Fix case files for 3u and 4u tops, add 2x2u thick plate
    [2u Thick Plate.stl, 3u Top.stl, 4u Top.stl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]
2023-03-29 More 2u changes
    [2u Thick Plate.stl, 2x2u Plate.dxf, 2x2u Thick Plate.stl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]
2023-07-15 Add symmetric case files, rename some files for Windows compat
    [4u 2x2u Top.stl, symmetric_cutiepie_4u_plate.dxf, symmetric_cutiepie_4u_top.step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]
2023-07-17 initial ortho pcb commit
    [BOM-cutiepie2040.csv, MCU.kicad_sch, Misc.kicad_sch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]
2023-07-17 finish routing ortho pcb, currently untested
    [BOM-cutiepie2040.csv, BOM-cutiepie2040_ortho.csv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]
2023-08-01 Finalized ortho pcb?
    [symmetric_cutiepie_4u_top v1.stl, symmetric_cutiepie_weight v1.stl]
2023-08-11 Ortho pcb and firmware donezo
    [Universal Ortho Plate (edited for 0.2 kerf).dxf]
2023-08-12 add kicad project files for fully tested uniform stagger hotswap pcb and several plates to support standard stagger and 2u stabilizers
    [MCU-hotswap.kicad_sch, Switch Matrix-hotswap.kicad_sch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]
2023-08-12 add kicad project files for untested standard stagger hotswap pcb
    [MCU-standard-stagger.kicad_sch, Switch Matrix-standard-stagger.kicad_sch, cutiepie2040-standard-stagger-BOM.csv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]
2023-09-01 Update ortho plate files
    [Universal Ortho Plate (edited for 0.2 kerf).dxf, Universal Ortho Plate.dxf, cutiepie ortho plate v10.3mf]
2023-09-25 add 'universal' ortho plus dual-stagger plate
    [MCU-hotswap.kicad_sch, Switch Matrix-hotswap.kicad_sch, cutiepie2040-dual-stagger-hotswap-pcb.kicad_pcb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]
2023-09-25 add gerbers for 'universal' plate
    [ortho-dual-stagger-cutiepie-plate-B_Cu.gbl, ortho-dual-stagger-cutiepie-plate-B_Mask.gbs, ortho-dual-stagger-cutiepie-plate-B_Paste.gbp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]
2023-09-25 upload accurate fabrication files for dual-stagger hotswap PCB
    [Switch Matrix-hotswap.kicad_sch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]
2023-10-08 update readme. add hotwap + solder orthopie pcb, howswap dual stagger pcb, and several fr4 plate gerbers for various cutiepie/orthopie layouts.
    [MCU.kicad_sch, Misc.kicad_sch, Switch Matrix.kicad_sch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]
2023-12-03 Updated fabrication files for dual-stagger and ortho PCBs and plates. Added stabilizer support for dual-stagger ISO P-key. Updated readme. Updated part mumbers in BOMs and corrected position files. A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
    [MCU-hotswap.kicad_sch, cutiepie-nRF52840-uniform-stagger-hotswap-pcb.kicad_pcb, cutiepie-nRF52840-uniform-stagger-hotswap-pcb.kicad_sch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]
2023-12-11 add symmetrical ortho case top with middle blocker
    [cutiepie2040-dual-stagger-hotswap-bom.csv, symmetric_cutiepie_4u_top_ortho_blocker_v1.step, symmetric_cutiepie_4u_top_ortho_blocker_v1.stl]
2024-01-21 added thick plate models
    [cutiepie-ortho-thick-plate v1.f3d, cutiepie-ortho-thick-plate v1.step, cutiepie-ortho-thick-plate v1.stl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]
